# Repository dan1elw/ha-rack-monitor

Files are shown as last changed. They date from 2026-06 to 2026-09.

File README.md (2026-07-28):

# Rack Monitor

<div align="center">
    Rack Monitor logo
</div>

ESP32-based temperature monitoring and fan control for a 10-inch homelab rack, fully integrated into Home Assistant via ESPHome. The controller measures rack and intake air temperatures and drives two PWM fans along a delta-T fan curve — cooling scales with the actual heat load instead of a fixed schedule. All sensors and controls are exposed as native Home Assistant entities.

## Features

- Temperature monitoring of two rack zones plus intake air reference
- Automatic fan control with hysteresis and a safety override
- Manual mode: any manual fan interaction pauses the automation
- Fan speed (RPM) monitoring per fan
- OTA updates, web interface for direct diagnostics, status LED
- custom HACS home assistant cards

## Repository layout

| Path | Content |
| ---- | --- |
| `esphome/` | ESPHome configuration (`rack-monitor.yaml`) |
| `analysis/` | Analysis and supporting tools. (e.g., Fan Curve Simulation, Temperature Cooling Efficiency) |
| `docs/` | Documentation (hardware, control logic, setup) |
| `home-assistant/` | custom HACS home assistant dashboard cards |

## Documentation

- [Temperature control](docs/temperature-control.md) — control logic, fan curve, simulation
- [Rack build](docs/rack-build.md) — 10-inch server rack build with aluminium profiles
- [ESP Commissioning](docs/esp-commissioning.md) — initial bring-up of the ESP32
- [PCB Design](docs/pcb/README.md) — design of the rack-monitor PCB board

## License

MIT © dan1elw

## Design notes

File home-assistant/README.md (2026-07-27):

# Rack Monitor Card







Minimalist Lovelace card for the `ha-rack-monitor` project: three temperature
tiles, two fan rows (RPM · PWM %), an online badge with last update, and an
optional mode bar bound to the firmware's mode select.



<div style="text-align: center;">
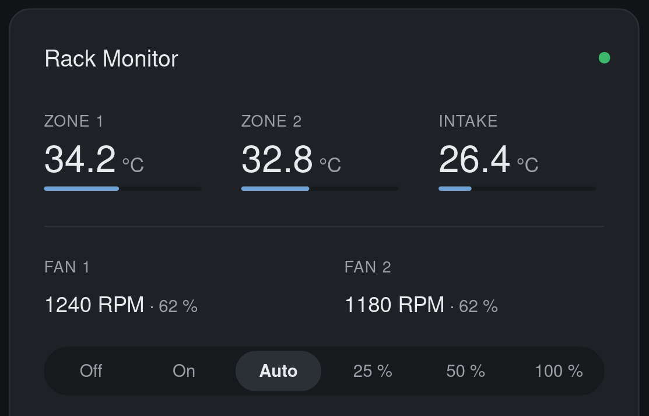
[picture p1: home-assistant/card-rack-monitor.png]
    
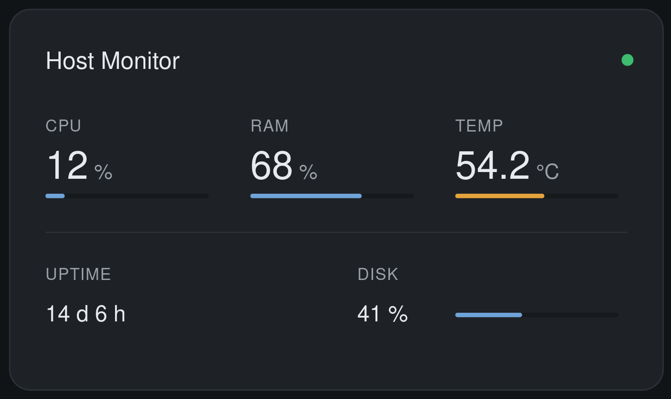
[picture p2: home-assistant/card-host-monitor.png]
    
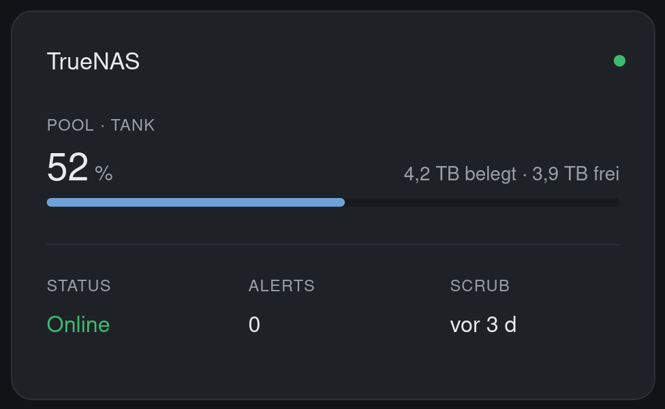
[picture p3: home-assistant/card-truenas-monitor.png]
    
</div>

## Installation (HACS)

1. HACS → Custom repositories → add this repository as type **Dashboard**.
2. Install **Rack Monitor Card** and reload the browser.

The built `rack-monitor-card.js` is attached to every GitHub release by CI.

## Configuration

The card ships with a guided visual editor: every field is an entity picker
filtered to matching entities (temperature sensors, fans, select, connectivity).

YAML equivalent:

```yaml
type: custom:rack-monitor-card
title: Rack Monitor
zone1_entity: sensor.rack_monitor_zone_1_temperature
zone2_entity: sensor.rack_monitor_zone_2_temperature
intake_entity: sensor.rack_monitor_intake_temperature
fan1_entity: fan.rack_fan_1
fan1_rpm_entity: sensor.rack_fan_1_rpm
fan2_entity: fan.rack_fan_2
fan2_rpm_entity: sensor.rack_fan_2_rpm
mode_entity: select.rack_monitor_mode        # optional, shows the mode bar
status_entity: binary_sensor.rack_monitor_status  # optional
```

| Option | Required | Description |
| --- | --- | --- |
| `zone1_entity` … `intake_entity` | yes | Temperature sensors |
| `fan1_entity`, `fan2_entity` | no | Fan entities (PWM duty from `percentage`) |
| `fan1_rpm_entity`, `fan2_rpm_entity` | no | Tachometer sensors |
| `mode_entity` | no | Firmware mode select; hidden if omitted |
| `status_entity` | no | Connectivity sensor; falls back to sensor availability |
| `zone1_name` … `fan2_name` | no | Custom labels |

## Development

```bash
cd home-assistant
npm ci
npm run build   # → dist/rack-monitor-card.js
```

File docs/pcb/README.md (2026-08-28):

# PCB

A PCB is a printed circuit board that mechanically supports and electrically connects electronic parts using tiny copper tracks. It acts as the core base for electronics like phones, computers, and toys.

## Schematic

The schematic drawing shows all connections and parts. It serves as a baseline for the later PCB-design. The complete design is done with [easyEDA](https://easyeda.com/). The sources are stored in the respective `json`-files. There are several nets introduced in the schematic: 3V3, 5V, 12V and GND.

<div align="center">
    
</div>

## PCB-Design

By designing the PCB, you place all components on the board and perform the wiring. The board has a size of `80x65mm`. For each part, you first need to define the related footprint, which is in some cases very specific, measure your existing HW-components carefully! In the following pictures you can see (1) top / front side and (2) bottom / back side of the PCB-board.

<div align="center">
    
    
</div>

Track sizes are defined by current. In the existing setup we have: (1) ESP32 with 250mA (and up to 500mA during Startup) (2) LED's with ~ 150mA (3) temperature sensors with max. 5mA in total (4) the two PWM fans with up to 600 mA and even higher during startup. In total we expect 1.2 - 2 A. To allow these ammount of current, the track sizes are set as follows:

| net | width | clearance |
| --- | ----- | --- |
| GND | 2mm | 0.4mm |
| 12V | 2mm | 0.2mm |
| 5V | 0.8mm | 0.2mm |
| 3V3, Data, etc. | 0.3mm | 0.2mm |

The GND is realized as GND-Planes on top and vorrom side instead of tracks. This allows good flow and reduces noise. In the following picture you can see the final PCB (remark: only the top layer is shown).

<div align="center">
    
</div>

And the 3D-Model with components:

<div align="center">
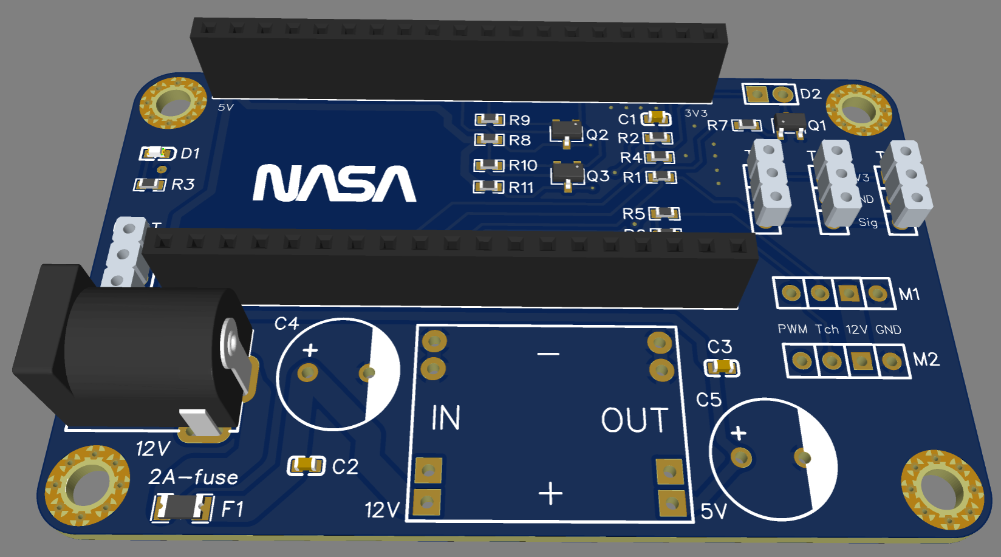
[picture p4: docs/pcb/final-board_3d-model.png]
    
</div>

## PCB Production

A **Gerber** file is a standard file format used to tell a PCB manufacturer how to make a printed circuit board (PCB). It contains layout data for each PCB layer, such as: copper traces, solder masks, markings, board outline, holes, etc...

A typical PCB oder includes multiple Gerber files (one per layer) plus drill files for holes. The manufacturer uses them to fabricate and assemble the board. For this project you can find all related gerber-files in `docs/pcb/gerber/`. The zipped version is attached to the latest release: [ha-rack-monitor/releases/latest](https://github.com/dan1elw/ha-rack-monitor/releases/latest).

The design is done with EasyEDA. The [gerber-files](https://docs.easyeda.com/en/PCB/Gerber-Generate/) are generated inside this tool. They contain the following files:

| file | description | used for production |
| ---- | --- | --- |
| Drill_NPTH_Through.DRL | contains drill hole positions that does not need metallization on the inner wall, such as through holes | yes |
| Drill_PTH_Trough_Via.DRL | contains drill hole positions that needs metallization on the inner wall, for JLCPCB use only | yes |
| Drill_PTH_Through.DRL | contains drill hole positions that needs metallization on the inner wall, such as multi-layer pads | yes |
| Gerber_BoardOutlineLayer.GKO | contains the board shape for cutting the PCB board | yes |
| Gerber_BottomLayer.GBL | bottom copper foil layer | yes |
| Gerber_BottomSilkscreenLayer.GBO | bottom silkscreen layer | yes |
| Gerber_BottomSolderMaskLayer.GBS | the board is covered with oil by default, the elements drawn in this layer correspond to the areas on bottom layer without oil | yes |
| Gerber_DocumentLayer.GDL | record PCB remarks | no |
| Gerber_TopLayer.GTL | top copper foil layer | yes |
| Gerber_TopSilkscreenLayer.GTO | top silkscreen layer | yes |
| Gerber_TopSolderMaskLayer.GTS | the board is covered with oil by default, the elements drawn in this layer correspond to the areas on top layer without oil | yes |

## PCBA (PCB Assembly)

A **PCBA** is a PCB (Printed Circuit Board) with electronic components mounted and soldered onto it. The PCB provides the electrical connections and mechanical support, while the components provide the actual functions of the circuit.

SMD stands for Surface-Mount Device. SMD components are electronic components designed to be mounted directly onto the surface of a PCB, rather than inserted through holes. Common SMD components include: Resistors, Capacitors, Diodes, ICs (integrated circuits), Transistors

In simple terms:
PCB = the board → SMD components = components mounted on the board → PCBA = the finished board with components assembled.

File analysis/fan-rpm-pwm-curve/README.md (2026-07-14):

# Fan RPM Sweep Tool

Measures the RPM-vs-percent curve of a Home Assistant fan entity and plots it.

## Files

- `ha_client.py` — reusable HA REST API client (token auth, state reads, service calls)
- `fan_sweep.py` — sweep test: ramps percentage, waits for stable RPM, writes CSV
- `plot_fan_curve.py` — plots one or more sweep CSVs (RPM vs. %)

## Setup

1. **Create a long-lived access token** in HA: Profile → Security → Long-lived access tokens → Create.
2. **Install dependencies** (only `requests` for the sweep, `matplotlib` for plotting):
   ```bash
   pip install requests matplotlib
   ```
3. **Export credentials:** (credentials can also be provided as arguents --url and --token)
   ```bash
   export HA_URL="http://<HA-IP>:8123"
   export HA_TOKEN="<token>"
   ```

## Run a sweep

```bash
python3 analysis/fan-rpm-pwm-curve/fan_sweep.py \
  --fan fan.rack_monitor_luefter_1 \
  --rpm-sensor sensor.rack_monitor_luefter_1_drehzahl \
  --start 0 --stop 100 --step 5 \
  --output analysis/fan-rpm-pwm-curve/fan1_curve.csv \
  --url http://<HA-IP>:8123 \
  --token <token>
```

Key parameters:

| Flag | Default | Meaning |
|---|---|---|
| `--window` | 4 | consecutive fresh sensor updates required for stability |
| `--tolerance` | 50 | max RPM spread within the window |
| `--poll` | 1.0 s | API poll interval (only *new* sensor updates count) |
| `--timeout` | 90 s | max settle time per step; result flagged `stable=False` |
| `--no-restore` | off | skip restoring the initial fan state at the end |

CSV columns: `timestamp, percent, rpm_mean, rpm_min, rpm_max, rpm_std, n_samples, stable, settle_s`.

Ctrl+C aborts cleanly: partial CSV is written and the fan state is restored.

## Plot

```bash
python3 analysis/fan-rpm-pwm-curve/plot_fan_curve.py \
    fan1_curve.csv \
    fan2_curve.csv \
    --output analysis/fan-rpm-pwm-curve/fan_curves.svg
```

Multiple CSVs overlay in one chart (e.g. Fan 1 vs. Fan 2, or before/after PCB Rev A). Min/max band shown as shaded area; unstable points circled in red.

## Notes for rack-monitor firmware

- Setting the percentage from HA triggers the **manual override** (`auto_writing` flag), so the temperature lambda will not fight the sweep. Verify the override does not auto-revert during a step (worst case ~90 s per step).
- Stability detection counts only *fresh* sensor updates (`last_updated` change), so it works regardless of the tach sensor's ESPHome `update_interval`. With a long `update_interval`, increase `--timeout` accordingly (timeout ≥ window × update_interval × 2 is a safe rule).
- After the run, re-enable automatic control per your firmware's override-exit mechanism if restore-to-previous-percentage is not sufficient.

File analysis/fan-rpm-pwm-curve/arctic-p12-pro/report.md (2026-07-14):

# Testreport - Arctic P12 Pro 12V PWM Fan

The [Arctic P12 Pro](https://www.arctic.de/en/P12-Pro/ACFAN00305A) fan has the following specifications:

| Specification | Value |
| --- | ----- |
| weight | 183 g |
| fan-speed |  600–3000 rpm, PWM controlled; 0 rpm below 5 % PWM |
| air-flow | 77 cfm; 131 m³/h |
| static-pressure |  6.9 mm H^2O |
| Typical Voltage | 12 V DC |
| Start Up Voltage | 3.3 V DC |
| Current | 0.33 A |

## Testcase

The Arctic P12 Pro Fans should be checked on their PWM to Fan Speed relationship. Therefore we are performing an automated testcase sweeping from 0 to 100% PWM and read out the fan speed in RPM. The test is performed in two test zones: 

1. between 0 % and 20 % with 1 % steps 
2. between 25 % and 100 % with 5 % steps

This difference is because we want to find out the minimum applicable fan speed setting.

## Testresults

The testresults can be seen in the following plot:

<div style="text-align: center;">
    
</div>

There are mainly three major findings:

1. The maximum Fan Speed at 100% is: **3030 rpm**
2. The minimum Speed, where the fan is actually on is: **6 % with ~500 rpm** (The specification is wrong at this point, it actually is "0 rpm below or equal 5 % PWM"). But when the fan is already ON and is step by step reduced in it's speed down to 2 %, the fan is still ON with ~399 rpm. This will not work, if you try to turn the fan ON with 2 %, it has to be ON before.
3. The Speed is following a linear function: **rpm = 27 * pwm + 332**

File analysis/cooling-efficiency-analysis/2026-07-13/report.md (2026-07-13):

# Cooling Analysis Report 2026-07-13

The following report is showing the testresults of a cooling analysis test.

## Testcase

The rack-monitor and its fans and cooling capabilities are tested in three fan settings: 30%, 60% and 100%. The fans are mounted on the back and on the right side of the rack. The temperature sensors are located (T1) behind the mac mini underneath the internal fan outlet (T2) on top of the mac mini between both SSDs. The Intake temperature is taken directly in front of the side fan. Both fans are pulling air into the rack, not out. Every test was taken for exactly 1h.

## Testresults

The testresults are shown in the plot below:

<div style="text-align: center;">
    
</div>

The Intake temperature was nearly the same, with 25.4°C, in each test run. It is very good visible, that for Temperature Sensor 2, the effect of higher fan speed is very relevant on the cooling efficiency. With 100% fan speed, we can cool down around 7°C. Temperature Sensor 1 is not that efficient, and the effect of higher fan speed is not that high. There we can cool down aroung 4°C.

One thing to mention is, that for both sensors and for each fan speed, there seems to be a min. temperature.

| sensor | speed | min. temperature |
| --- | ----- | --- |
| 1 | 30% | 28.1 °C |
| 1 | 60% | 27.7 °C |
| 1 | 100% | 27.4 °C |
| 2 | 30% | 31.7 °C |
| 2 | 60% | 30.5 °C |
| 2 | 100% | 29.1 °C |

## Next Steps

The current automated fan curve is always giving 100% fan speed, as the temperature in the rack is pretty high compared to the environmental temperature. To mitigate this, we will adapt the fan control delta_T variable.

What else needs to be done is the position and orientation of the fans. The Mac Mini has the fan inlet at the bottom of the device and outlet on the back. Ideal would be to have a fan on the buttom, pulling air into the Mac and one on the back pulling the air outside of the rack. This setup should be evaluated.

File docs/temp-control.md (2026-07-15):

# Temperature Control

Automatic fan curve, evaluated every 15 s while `auto_mode` is on. The controller writes to the fan **entities** (not the raw PWM outputs), so Home Assistant always shows the true on/off state and speed.

**Control variable:** ΔT = `max(rack_temp_1, rack_temp_2) − intake_temp` — the warmer rack DS18B20 against the intake air reference. `fmaxf` is used, so one dead rack sensor does not block the control loop. If both rack sensors return NaN, no action is taken.

**Primary curve (delta-T mode):**

| ΔT | PWM |
|---|---|
| `< 9 °C` | 0 % |
| `9 .. 10 °C` | hysteresis: 0 % if previously off, 10 % if previously on |
| `10 .. 18 °C` | linear 10 → 100 % |
| `≥ 18 °C` | 100 % |

**Fallback (intake sensor NaN):** absolute curve on `max(rack_temp)` — on ≥ 35 °C, off < 34 °C (1 °C hysteresis), linear 10 → 100 % across 35-45 °C.

**Override (safety net):** `max(rack_temp) ≥ 45 °C` forces 100 %, regardless of mode.

The 1 °C hysteresis (in both modes) prevents on/off flutter at the switching threshold. All thresholds are hardcoded in the lambda.

**Manual override:** any manual fan interaction (HA card or web UI — on/off or speed) switches `auto_mode` off automatically. Changes made by the controller itself and the boot restore (first 10 s) are ignored. Re-enable via `switch.luefter_automatik`; the curve takes over on the next 15 s cycle.

**HA entities:** `switch.luefter_automatik` (enable), `sensor.rack_delta_t` (ΔT, for tuning), `fan.luefter_1` / `fan.luefter_2` (manual control while `auto_mode` is off).

**Source:** `interval: 15s → lambda` in `rack-monitor.yaml`.

## Simulated temperature control

With the scripts provided in `analysis/temperature-control-algo`, you can simulate the C++ code embedded in `rack-monitor.yaml`:

```
python3 fan_curve_plot.py [path/to/rack-monitor.yaml]
```

The script extracts the original lambda from the YAML, compiles it with g++ (fan entities and hysteresis state are stubbed in a small harness), and sweeps ΔT up and down as well as the absolute fallback range — the YAML remains the single source of truth. Each scenario runs in an isolated controller instance so the hysteresis branches are visible in the plot.

<div style="text-align: center;">
    fan curve
</div>

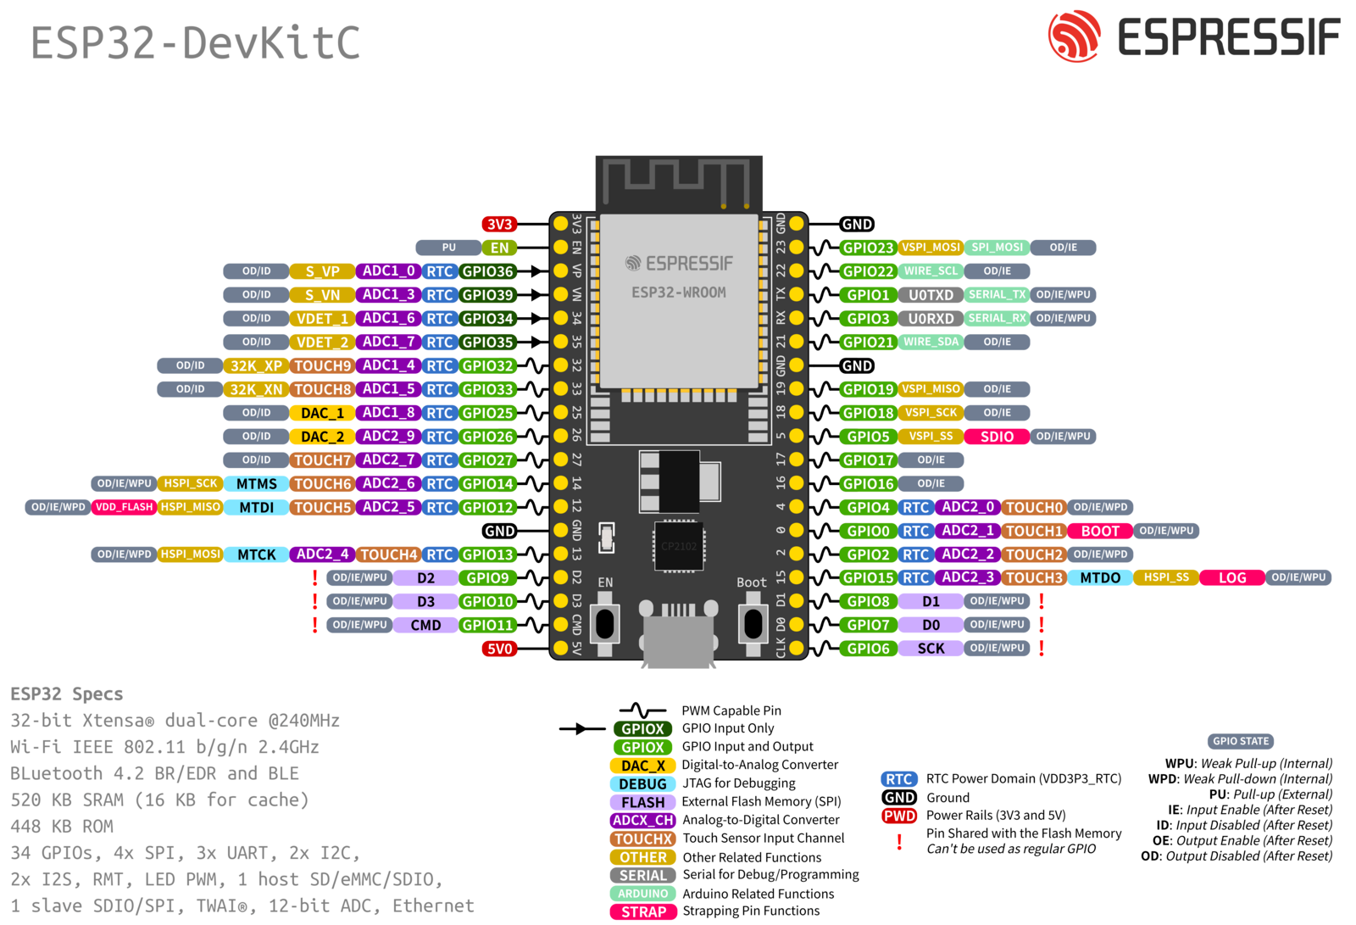
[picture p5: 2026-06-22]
docs/components/esp32_38pin_pinout.png

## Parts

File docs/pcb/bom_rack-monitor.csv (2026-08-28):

ID | Name | Designator | Footprint | Quantity | Manufacturer Part | Manufacturer | Supplier | Supplier Part | Price
1 | 1000u | C4,C5 | ELKO-D10-5.08MM | 2
2 | ESP-Left | U2 | HDR-TH_19P-P2.54-V-F | 1 | PM254-1-19-Z-8.5 | HCTL(华灿天禄) | LCSC | C2897382 | 0.346
3 | ESP-Right | U3 | HDR-TH_19P-P2.54-V-F | 1 | PM254-1-19-Z-8.5 | HCTL(华灿天禄) | LCSC | C2897382 | 0.346
4 | POWER-JACK | 12V | DC_12V_POWER-JACK | 1 | POWER-JACK | 索峰 | LCSC | C9900001795
5 | 1uF | C1 | C0603 | 1 | CL10B105KA8NNNC | SAMSUNG(三星) | LCSC | C29936 | 0.022
6 | 100nF | C2,C3 | C0603 | 2 | CL10B104KA8NNNC | SAMSUNG(三星) | LCSC | C1590 | 0.016
7 | HSMG-C190 | D1 | LED-SMD_L1.6-W0.8-R-RD | 1 | HSMG-C190 | Broadcom(博通) | LCSC | C188729 | 0.203
8 | LED-Stripe | D2 | CON1X2 | 1
9 | S8050 | Q1 | SOT-23-3_L3.0-W1.7-P0.95-LS2.9-BR | 1 | S8050 J3Y(RANGE:200-350) | CJ(江苏长电/长晶) | LCSC | C2146 | 0.017
10 | BSS138 | Q2,Q3 | SOT-23-3_L2.9-W1.6-P1.90-LS2.8-BR | 2 | BSS138 | onsemi(安森美) | LCSC | C52895 | 0.066
11 | 4.7kΩ | R1 | R0603 | 1 | 0603WAF4701T5E | UNI-ROYAL(厚声) | LCSC | C23162 | 0.003
12 | 10kΩ | R2,R4,R5,R6,R8,R9,R10,R11 | R0603 | 8 | 0603WAF1002T5E | UNI-ROYAL(厚声) | LCSC | C25804 | 0.005
13 | 2.2kΩ | R3 | R0603 | 1 | 0603WAF2201T5E | UNI-ROYAL(厚声) | LCSC | C4190 | 0.003
14 | 1kΩ | R7 | R0603 | 1 | 0603WAF1001T5E | UNI-ROYAL(厚声) | LCSC | C21190 | 0.003
15 | MP1584EN | U4 | MP1584EN_ALI | 1 | MP1584EN_moudle | null | LCSC | C9900223542
16 | MNT | U10,U11,U12,U13 | HOLE_M3_PTH | 4 | 3mm mounting hole
17 | Debug | UART | CON1X03 | 1
18 | 2A-fuse | F1 | F1206 | 1 | SF-1206F200-2 | BOURNS | LCSC | C719183 | 1.286
19 | DS18B20 | T3,T2,T1 | CON1X03 | 3
20 | PWM-Fan | M1,M2 | CON1X04 | 2

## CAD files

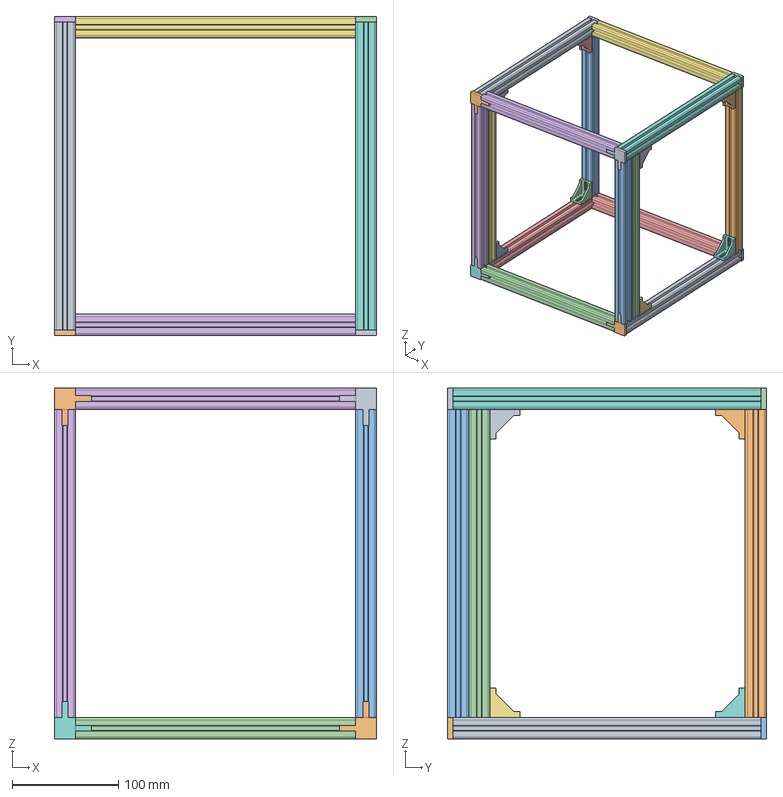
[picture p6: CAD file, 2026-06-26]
docs/cad-rack/assembly.FCStd
303.0 x 300.0 x 330.0 mm
profil290_001
ecke_001
profil290_002
profil290_003
profil290_004
profil290_005
profil290_006
profil290_007
profil290_008
profil290_009
profil290_010
profil263_001
profil263_002
profil263_003
profil263_004
ecke_002
ecke_003
ecke_004
ecke_005
ecke_006
ecke_007
ecke_008
winkel_001
winkel_002
winkel_003
winkel_004
winkel_005
winkel_006
winkel_007
winkel_008

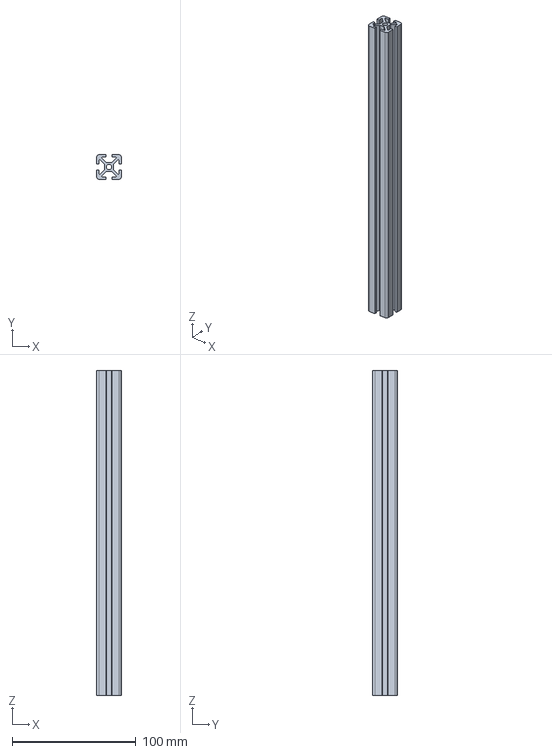
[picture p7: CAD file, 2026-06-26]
docs/cad-rack/alu-profil-20x20x263.FCStd
20.0 x 20.0 x 263.0 mm

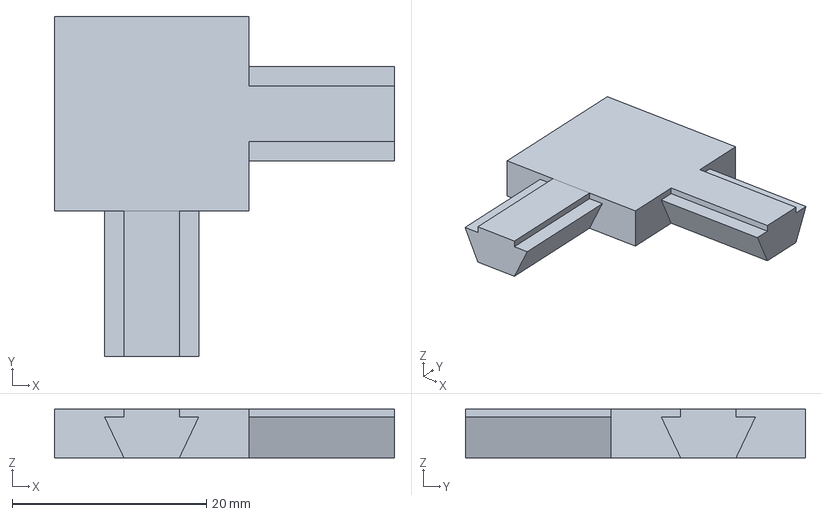
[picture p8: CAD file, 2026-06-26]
docs/cad-rack/alu-ecke-20x20.FCStd
35.0 x 35.0 x 5.00 mm

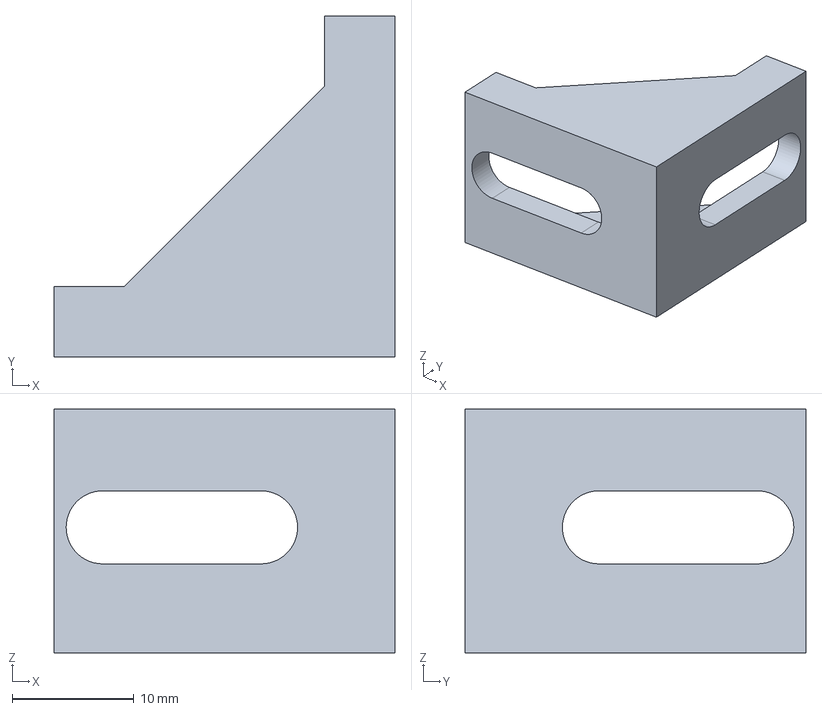
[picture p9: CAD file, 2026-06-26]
docs/cad-rack/alu-winkel-20x20x28.FCStd
28.0 x 28.0 x 20.0 mm

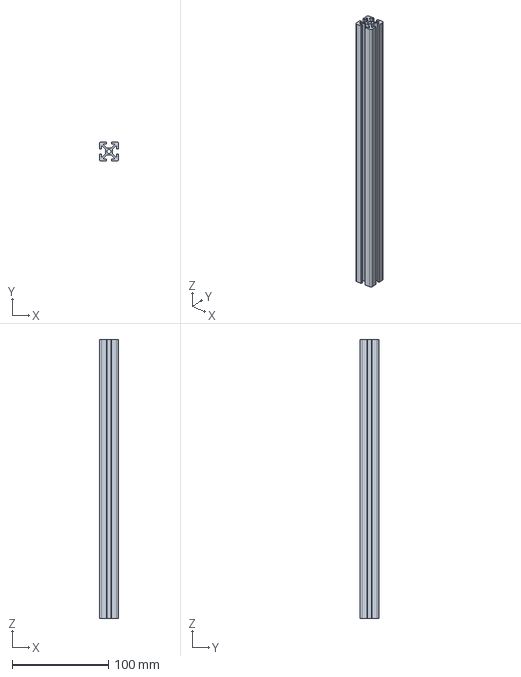
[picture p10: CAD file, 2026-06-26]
docs/cad-rack/alu-profil-20x20x290.FCStd
20.0 x 20.0 x 290.0 mm

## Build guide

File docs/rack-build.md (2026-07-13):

# Server-Rack with Aluminium-Profiles

## Decisions taken during design process

As I want to build a home-lab style server-rack, which can fit onto my desk, and also supports a lot of stock equipment, it will be realized as a `10 inch` server-rack. This results in the following dimensions:

aluprofil

I decided to build the rack itself with Aluminium Profiles with the size of `20 x 20 mm`. 

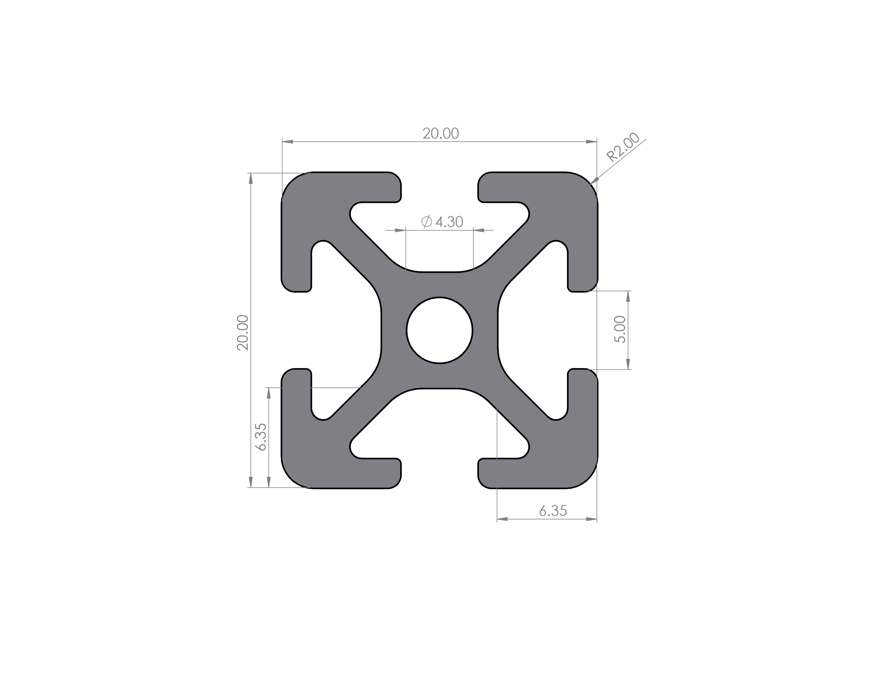
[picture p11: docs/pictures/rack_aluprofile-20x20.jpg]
aluprofil


<br>Furthermore I want this rack to fit inside an Ikea Kallax shelf. This has inside dimensions of `33.5 x 33.5 cm`. By taking into account some space for an anti-scratch tape, the max. height of the server rack is limited to `33 cm`.

## Design of the rack

The rack is designed in FreeCAD. The files can be found here: `../docs/cad-rack/`. The final rack has the outer dimensions (H, B, T): `330 mm`, `303 mm`, `300 mm`.

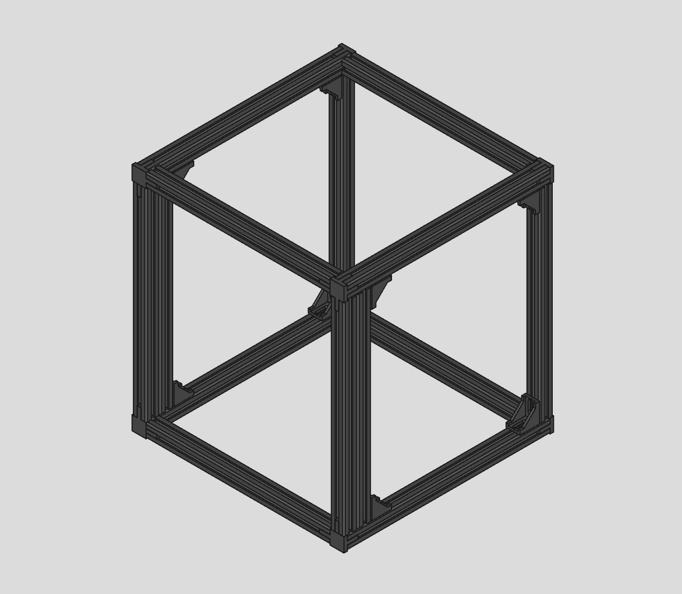
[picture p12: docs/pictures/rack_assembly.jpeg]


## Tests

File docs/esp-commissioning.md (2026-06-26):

# Rack Monitor — First Commissioning & Home Assistant Integration

Initial bring-up of the ESP32 (`rack-monitor`) with ESPHome and integration into Home Assistant.

> **Device name `rack-monitor` is fixed.** HA integration, OTA, and mDNS are configured against it — do not rename.

---

## Prerequisites

| Item | Requirement |
|---|---|
| Hardware | ESP32-WROOM-32 DevKitC (CP2102, USB-C) |
| Firmware config | `rack-monitor.yaml` (validated), `secrets.yaml` |
| Dev machine | Ubuntu, user in `dialout` group |
| Tooling | ESPHome 2026.5.x |
| Network | router static DHCP lease prepared for the device |

```bash
# One-time: grant serial access (restart required)
sudo usermod -aG dialout $USER
```

---

## Step 1 — Power & Connect (Initial Flash Only)

The first flash **requires a physical USB connection**.

> ⚠️ **Do not power VIN and USB at the same time.** Parallel 12 V (buck) + USB power overloads the USB supply and breaks the serial connection. For flashing, use USB only — leave the 12 V rail disconnected.

1. Disconnect the 12 V input / MP1584 output from the ESP32.
2. Connect the ESP32 to the Ubuntu machine via USB-C.
3. Confirm the port is present:

```bash
ls /dev/ttyUSB*
```

---

## Step 2 — Flash the Firmware

Initial flash over USB (subsequent updates go via OTA):

```bash
esphome run rack-monitor.yaml
```

Select the USB serial port when prompted. After the build completes, the device flashes, reboots, and begins streaming boot logs.

---

## Step 3 — Capture DS18B20 ROM Addresses

The two DS18B20 sensors report their ROM addresses in the boot log on first run. These must be entered into the YAML manually so each sensor maps to a fixed entity.

1. In the boot log, locate the 1-Wire scan (GPIO4) listing both ROM addresses.
2. Copy each address into the corresponding sensor block in `rack-monitor.yaml`.
3. Re-flash to apply:

```bash
esphome run rack-monitor.yaml
```

> Without fixed ROM addresses, sensor-to-entity assignment can swap between boots — critical, since the DS18B20 readings drive the fan curve.

---

## Step 4 — Switch to Final Power

Once flashing is complete and verified:

1. Disconnect USB.
2. Connect the 12 V supply (MP1584 → 5 V rail).
3. The device boots, joins WiFi, and is reachable via:
   - Web server on port **80** (`http://rack-monitor.local` or its static IP)
   - mDNS hostname `rack-monitor.local`

Confirm the router has assigned the reserved static lease.

---

## Step 5 — Integrate into Home Assistant

1. In HA: **Settings → Apps** install ESPHome Device Builder.
1. In HA: **Settings → Devices & Services** open ESPHome.
1. ESPHome auto-discovers `rack-monitor` via mDNS — confirm the prompt. (If not discovered, add manually via **+ Add Integration → ESPHome** using the static IP.)
1. When prompted, supply the **API encryption key** from `rack-monitor.yaml` (inline, Variante A).

### Exposed entities

| Entity | Type | Notes |
|---|---|---|
| `auto_mode` | Switch | Enables automatic fan curve |
| `target_temp` | Number | 25–45 °C, default 28 °C |
| DS18B20 ×2 | Sensor | Fan-control temperatures |
| BMP280 | Sensor | Display only (temp/pressure) |
| Fan PWM ×2 | Output | GPIO25 / GPIO26 |
| Tachometer ×2 | Sensor | RPM, GPIO32 / GPIO33 |
| Diagnostics | Sensors | Uptime, WiFi signal, ESP32 internal temp, IP, status |
| Restart | Button | Remote reboot |

---

## Step 6 — Verify

- [ ] Device online in HA, status sensor reports connected
- [ ] Both DS18B20 readings plausible and distinct
- [ ] BMP280 reporting
- [ ] `auto_mode` and `target_temp` controllable from HA
- [ ] Web UI reachable on port 80
- [ ] Static IP held after reboot

---

## Subsequent Updates (OTA)

After the initial USB flash, all further updates run wirelessly — no physical connection needed:

```bash
esphome run rack-monitor.yaml   # select the OTA/network target
```

OTA password is stored in `secrets.yaml`.

---

## Troubleshooting

| Symptom | Likely cause | Fix |
|---|---|-----|
| No `/dev/ttyUSB*` | Missing `dialout` membership | `usermod -aG dialout`, re-login |
| Serial drops during flash | VIN + USB powered together | Use USB only for flashing |
| Sensors swap between boots | ROM addresses not fixed | Enter ROM addresses from boot log |
| Not discovered in HA | mDNS not resolving | Add manually via static IP |
| IP changes after reboot | DHCP lease not reserved | Set static lease in router settings |

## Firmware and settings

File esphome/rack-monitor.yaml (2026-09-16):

# =============================================================
# ha-rack-monitor (c) dan1elw
# https://github.com/dan1elw/ha-rack-monitor
# version 1.3
# =============================================================
# Rack-Controller – ESP32-WROOM-32 DevKitC (38-Pin)
# Temperaturüberwachung (DS18B20) + PWM-Lüftersteuerung (Delta-T)
# Anbindung: Home Assistant via native ESPHome-API
# =============================================================
# Pinbelegung:
#   GPIO4   1-Wire-Bus DS18B20 (4,7 kΩ Pull-up extern)
#   GPIO12  Status-LED gelbgrün (2,2 kΩ Vorwiderstand gegen GND)
#           Strapping-Pin (MTDI): muss beim Boot LOW sein
#           -> kein Pull-up an diesem Pin zulässig
#   GPIO21  I²C SDA – reserviert (Sensor noch nicht konfiguriert)
#   GPIO22  I²C SCL – reserviert
#   GPIO25  PWM Lüfter 1 (25 kHz, via Level-Shifter)
#   GPIO26  PWM Lüfter 2 (25 kHz, via Level-Shifter)
#   GPIO32  Tacho Lüfter 1 (10 kΩ Pull-up extern)
#   GPIO33  Tacho Lüfter 2 (10 kΩ Pull-up extern)
# =============================================================

esphome:
  name: rack-monitor
  friendly_name: Rack Monitor

esp32:
  board: esp32dev
  framework:
    type: arduino

logger:

# ---------- Konnektivität ----------
# API-Key ist gerätespezifisch und bleibt bewusst inline
# (nicht in secrets.yaml auslagern).
api:
  encryption:
    key: !secret api_encryption_key # hier den generierten key einfügen

ota:
  - platform: esphome
    password: !secret ota_password

wifi:
  ssid: !secret wifi_ssid
  password: !secret wifi_password
  ap:
    ssid: Rack-Monitor-Fallback
    password: !secret fallback_password

captive_portal:

# Weboberfläche zur Direktdiagnose: http://<IP>
web_server:
  port: 80

# ---------- Globale Variablen ----------
globals:
  # true, während die Automatik/Modus-Logik die Fan-Entitäten schreibt
  # -> verhindert, dass sie ihren eigenen manuellen Override auslöst
  - id: auto_writing
    type: bool
    initial_value: 'false'

  # true, während die Firmware den Modus-Select selbst umstellt
  # (z. B. manuelle Bedienung -> "On"); unterdrückt die on_value-Aktion
  - id: mode_syncing
    type: bool
    initial_value: 'false'

# ---------- Busse ----------
one_wire:
  - platform: gpio
    pin: GPIO4

# ---------- Sensoren ----------
sensor:
  # DS18B20 – feste ROM-Adressen verhindern Entitäten-Tausch nach Reboot
  - platform: dallas_temp
    address: 0x2e0000006c76c428
    id: rack_temp_1
    name: "Rack Temp 1"
    update_interval: 15s

  - platform: dallas_temp
    address: 0x9a0000006bd8df28
    id: rack_temp_2
    name: "Rack Temp 2"
    update_interval: 15s

  - platform: dallas_temp
    address: 0x990000006bf7c528
    id: intake_temp
    name: "Intake Temp"
    update_interval: 15s

  # Regelgröße: ΔT = heißester Rack-Sensor − Zuluft (für HA-Tuning sichtbar)
  - platform: template
    name: "Rack Delta T"
    id: rack_delta_t
    unit_of_measurement: "°C"
    accuracy_decimals: 1
    update_interval: 15s
    lambda: |-
      float rack = fmaxf(id(rack_temp_1).state, id(rack_temp_2).state);
      if (isnan(rack) || isnan(id(intake_temp).state)) return NAN;
      return rack - id(intake_temp).state;

  # Tacho: Arctic P12 Pro = 2 Impulse/Umdrehung -> Faktor 0,5
  - platform: pulse_counter
    pin:
      number: GPIO32
      mode: INPUT_PULLUP
    internal_filter: 13us
    name: "Luefter 1 Drehzahl"
    unit_of_measurement: "RPM"
    icon: mdi:fan
    filters:
      - multiply: 0.5
    update_interval: 10s

  - platform: pulse_counter
    pin:
      number: GPIO33
      mode: INPUT_PULLUP
    internal_filter: 13us
    name: "Luefter 2 Drehzahl"
    unit_of_measurement: "RPM"
    icon: mdi:fan
    filters:
      - multiply: 0.5
    update_interval: 10s

  # ---------- Diagnose ----------
  - platform: uptime
    name: "Uptime"
    update_interval: 60s

  - platform: wifi_signal
    name: "WiFi Signal"
    update_interval: 60s

  # Chip-Temperatur des ESP32 (nicht Rack-Temperatur)
  - platform: internal_temperature
    name: "ESP32 Temperatur"
    update_interval: 60s

# ---------- PWM-Ausgänge ----------
# 25 kHz gemäß Intel-4-Pin-Spezifikation (Arctic P12 Pro: 21–28 kHz)
output:
  - platform: ledc
    pin: GPIO25
    frequency: 25000 Hz
    id: pwm_fan1

  - platform: ledc
    pin: GPIO26
    frequency: 25000 Hz
    id: pwm_fan2
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

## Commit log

2026-07-14 Update findings in fan RPM PWM curve report
    Clarified the minimum fan speed specification and added details about fan behavior at low PWM values.
2026-09-16 Revise GPIO pin assignments and comments in YAML
    Updated GPIO pin assignments and configuration details in the rack-monitor.yaml file. Adjusted comments and corrected the status LED pin configuration.
    [rack-monitor.yaml]
